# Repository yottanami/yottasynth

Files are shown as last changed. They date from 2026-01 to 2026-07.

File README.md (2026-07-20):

# Yottasynth: Open Hardware Touchscreen Synth with Persian/Iranian Tunings

Yottasynth is an open hardware touchscreen synth with a compact page-based control surface, five context-sensitive knobs, an arpeggiator, a step sequencer, and support for Persian/Iranian music tunings.

یوتاسینث یک سینت‌سایزر دیجیتال متن‌باز با رابط لمسی، سکوئنسر، آرپژیاتور و پشتیبانی از کوک‌های موسیقی ایرانی است. این ساز امکان انتخاب کوک‌های مرتبط با دستگاه‌ها و آوازهای ایرانی را فراهم می‌کند تا برای اجرا و طراحی صدا در فضای موسیقی ایرانی مناسب‌تر باشد.

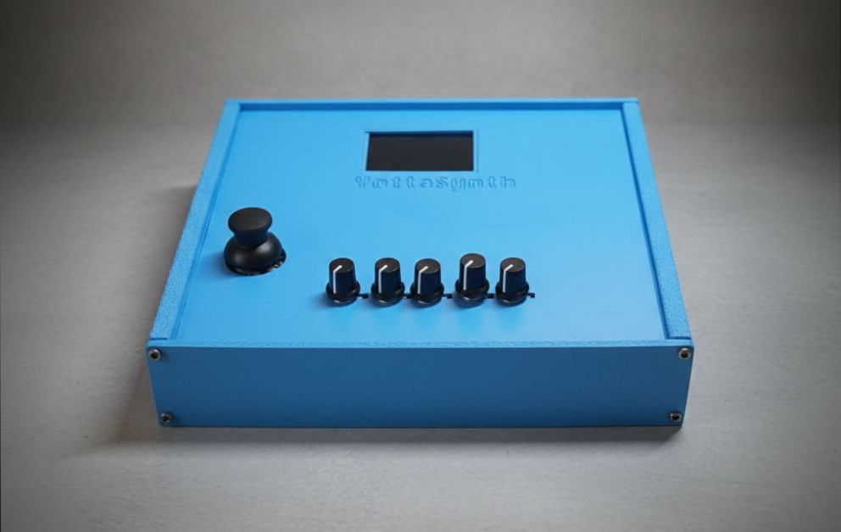
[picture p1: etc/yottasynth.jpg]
Yottasynth prototype

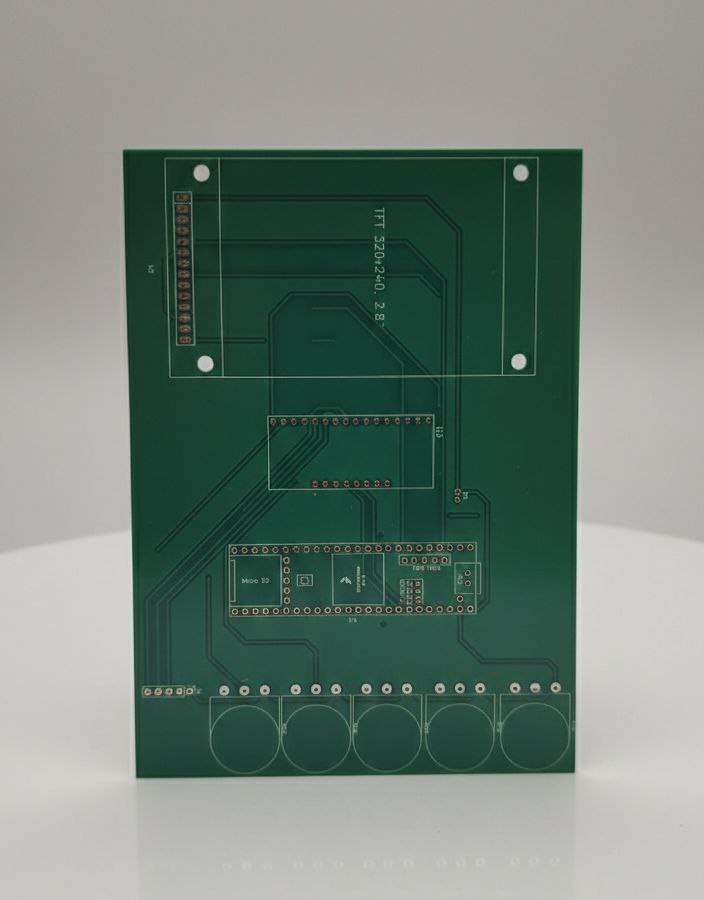
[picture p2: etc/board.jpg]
Yottasynth board


## What It Is

The current firmware is a playable mono synth instrument with:

- a touch-first panel UI
- five context-sensitive knobs
- arpeggiator
- 16-step sequencer
- three effect modes: `Echo`, `Reverb`, and `Drive`
- selectable Persian scale tunings

## Current Features

- `PLAY`, `OSC`, `FILT`, `MOD`, `FX`, `ARP`, `SEQ`, and `SET` pages
- mono synth voice with dual oscillators, noise, filter, envelope, glide, and LFO
- page-specific touch actions and knob mappings
- internal BPM transport, or external MIDI clock sync over USB
- arpeggiator with mode, division, gate, octave range, and latch
- 16-step sequencer with step selection, bank switching, swing, and live MIDI record
- effect editing with page-dependent controls
- output volume, tuning, and clock-source (internal / external) selection from the settings page
- Persian scale support through alternate tunings
- touch screen used for navigation and `OK / Confirm` actions

## Persian / Iranian Tunings

The current tuning list includes:

- `Standard` (`استاندارد`)
- `Shur` (`شور`)
- `Abuata` (`ابوعطا`)
- `Dashti` (`دشتی`)
- `Bayat-e Tork` (`بیات ترک`)
- `Afshari` (`افشاری`)
- `Segah` (`سه‌گاه`)
- `Chahargah` (`چهارگاه`)
- `Homayun` (`همایون`)
- `Bayat-e Esfahan` (`بیات اصفهان`)
- `Nava` (`نوا`)
- `Mahur` (`ماهور`)
- `Rast-Panjgah` (`راست‌پنجگاه`)

## How It Works

Yottasynth is organized as one compact panel split into pages. The touch screen is used to switch pages and trigger actions, while the five physical knobs always control the five parameters shown on screen for the current page.

In normal use, a MIDI controller feeds notes into the synth engine through USB host MIDI. You shape the sound on the synth pages, switch to `ARP` for rhythmic note patterns, use `SEQ` for step programming and live record, and adjust global volume or tuning in `SET`. When a destructive action needs confirmation, a second tap on the armed button acts as `OK`.

The transport (sequencer and arpeggiator) normally runs on its own internal BPM. Set `SYNC` to `EXT` on the `SET` page to slave it to an external MIDI clock over USB instead. Two USB paths are supported without any hardware change:

- the **USB host port** (alongside the keyboard, through a USB hub) for standalone gear such as an Ableton Move
- the **native USB port** (the same cable used to upload firmware) for a computer / DAW such as Ableton Live

In external mode the synth follows the host's tempo and its start / stop / continue transport.

## Interface Summary

- top bar: page title plus compact status
- middle panel: parameter cards and touch actions
- bottom bar: eight color-coded tabs

Page layout:

- `PLAY`: quick performance controls
- `OSC`: oscillator mix, noise, octave, detune, and waveform changes
- `FILT`: filter and envelope shaping
- `MOD`: LFO, bend range, and modulation target
- `FX`: echo, reverb, or drive editing
- `ARP`: arpeggiator setup
- `SEQ`: 16-step sequencing
- `SET`: output volume, tuning, clock source (internal / external sync), and input test entry

## User Guide

For a user-perspective walkthrough of the panel, controls, pages, and sequencing flow, see [docs/user-guide.md](docs/user-guide.md).

For developer-facing documentation of the firmware structure and code, see:

- [docs/README.md](docs/README.md)
- [docs/source-reading-guide.md](docs/source-reading-guide.md)
- [docs/codebase-guide.md](docs/codebase-guide.md)

## Screenshots

Yottasynth interface overview

To export screenshots of the current screen pages without running the device firmware:

```bash
python3 scripts/generate_screenshots.py
```

This writes one SVG per page, a stitched `overview.svg` for the README, and a simple preview index into `docs/screenshots/`.

## Hardware + 3D

- board design files: `etc/board/`
- touch-driven panel firmware: `src/`
- headers and shared definitions: `include/`
- project docs: `docs/`

## Status

This is still an active work-in-progress project, but the firmware already implements the main instrument shell and core performance workflow.

## Contributing

Contributions are welcome. Feel free to open an issue or a PR if you want to help with firmware, hardware, or design.

## Issues

https://github.com/yottanami/yottainst/issues/new

## Contact

https://yottanami.com

## Support

- GitHub Sponsors: https://github.com/sponsors/yottanami
- Ko-fi: https://ko-fi.com/yottanami

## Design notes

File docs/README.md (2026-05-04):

# Yottasynth Documentation

This folder contains the project documentation for two different audiences:

1. people who want to use the instrument
2. people who want to understand or change the firmware

If you are new to the codebase, read the documents in this order:

1. [User Guide](user-guide.md)
2. [Source Reading Guide](source-reading-guide.md)
3. [Codebase Guide](codebase-guide.md)

## Document Map

### End-user documentation

- [User Guide](user-guide.md)
  Explains the screen, pages, knobs, touch controls, and normal playing workflow.

### Developer documentation

- [Source Reading Guide](source-reading-guide.md)
  Explains the C++ language features and embedded-programming patterns used by this firmware.

- [Codebase Guide](codebase-guide.md)
  Explains how the firmware is structured, how data moves through it, and what each active file is responsible for.

- [Synth V1 Plan](synth-v1-plan.md)
  Historical product/UI planning notes for the current panel concept.

## Scope Notes

This repository contains both:

- the current firmware implementation in `src/` and `include/`
- older prototype code in `lib/`

The active firmware entry point is [`src/main.cpp`](../src/main.cpp). The `lib/` directory is still useful for historical context, but it is not the main implementation path described by the current firmware docs.

## Repository Areas

- `src/`
  Main firmware implementation.

- `include/`
  Header files for the active firmware.

- `docs/`
  Project documentation.

- `etc/`
  Hardware photos, board design files, and related assets.

- `lib/`
  Legacy prototype code and earlier experiments.

- `test/`
  Placeholder test directory. There are currently no automated firmware tests in this repository.

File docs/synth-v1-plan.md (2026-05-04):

# Yottasynth Synth V1

## Summary

This document is the practical reference for the current panel structure and touch UI.

The implemented interface provides:

- eight tabs
- five context-sensitive pots
- joystick push-button as `OK / Confirm`
- one main panel area that changes by page
- a dedicated sequencer grid view

## Hardware Control Map

Source of truth note:

- the active mux and panel mapping in code is the valid mapping
- board design documents may still reflect an older mux wiring layout
- if there is any conflict, follow the current firmware implementation

- mux select pins: `14 / 15 / 16 / 17`
- mux signal pin: `22`
- knob 1: `C2`
- knob 2: `C4`
- knob 3: `C1`
- knob 4: `C5`
- knob 5: `C0`
- joystick push button: `C7`
- touch screen: primary navigation and detailed editing

Joystick axes are intentionally unused in v1.

## UI Structure

- `PLAY`
  - pots: cutoff, resonance, glide, arp gate, BPM
  - touch actions: run/stop, arp toggle, unused slot, panic
- `OSC / MIX`
  - pots: osc1 mix, osc2 mix, noise mix, octave, detune
  - touch actions: osc1 previous wave, osc1 next wave, osc2 previous wave, osc2 next wave
- `FILTER / AMP`
  - pots: cutoff, resonance, attack, decay, release
  - touch actions: sustain down, sustain up, short envelope preset, long envelope preset
- `MOD`
  - pots: LFO rate, LFO depth, glide, bend range, LFO target
  - touch actions: LFO off, filter target, pitch target, zero depth
- `FX`
  - pots: mode-dependent effect parameters
  - touch actions: bypass, echo, reverb, drive
- `ARPEGGIATOR`
  - pots: BPM, division, gate, octave range, mode
  - touch actions: enable, latch, run/stop, clear held notes
- `SEQUENCER`
  - pots: BPM, pattern length, swing, selected-step note, selected-step gate
  - touch actions: run/stop, record arm, bank switch, clear pattern
  - touch step pads: select a step on first tap, toggle active state on second tap
- `SETTINGS`
  - pots: output volume, tuning
  - touch actions: input test page

The `OK` button confirms pattern clear when the sequencer page is waiting for confirmation.

## Interaction Rules

- the five pots stay active and remap by page
- the touch screen is the main navigation and action surface
- the joystick `OK` button is reserved for confirmations such as sequence clear
- sequencer step buttons use first tap to select and second tap to toggle
- page accent colors should stay stable across the whole interface

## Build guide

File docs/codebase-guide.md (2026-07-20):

# Yottasynth Codebase Guide

This document explains how the current firmware is structured, how the main modules work, and how the code is organized for someone who is new both to the project and to embedded C++.

It focuses on the active firmware path:

- [`src/`](../src/)
- [`include/`](../include/)

It also points out where the repository still contains older prototype code.

## 1. What This Firmware Does

At a high level, the firmware turns a Teensy-based hardware instrument into a touch-first mono synthesizer with:

- USB host MIDI input
- a five-knob control surface through a multiplexer
- a touchscreen interface built with LVGL
- a mono synth voice with two oscillators, noise, filter, envelope, glide, and LFO
- a transport shared by an arpeggiator and step sequencer
- three effect modes: echo, reverb, and drive
- selectable Persian/Iranian-inspired tuning tables

The main idea is simple:

1. read physical inputs
2. update application state
3. render the UI from that state
4. drive the synth engine from that state
5. repeat forever

## 2. Current Architecture

The active runtime looks like this:

```text
Hardware inputs
  |- touch controller
  |- five pots wired directly to analog pins 14/15/16/17/22
  |- USB MIDI device
  v
Input and event layers
  |- main.cpp touch callback
  |- ControlInput
  |- PlayMode
  v
Shared state and control logic
  |- AppState
  |- Settings
  |- MainMenu
  |- PerformanceEngine
  v
Audio layers
  |- Synth
  |- audio_setup.cpp audio graph + effects
  v
Audio codec / I2S output
```

Two design choices define the whole project:

1. `AppState` is the central shared data model.
2. `main.cpp` coordinates subsystems in a single cooperative loop.

## 3. Repository Structure

### Active firmware

- [`src/main.cpp`](../src/main.cpp)
  Boot sequence, LVGL setup, touchscreen input bridge, main runtime loop.

- [`src/app_state.cpp`](../src/app_state.cpp) and [`include/app_state.h`](../include/app_state.h)
  Central application state and label helpers.

- [`src/control_input.cpp`](../src/control_input.cpp) and [`include/control_input.h`](../include/control_input.h)
  Multiplexer-based knob and confirm-button scanning.

- [`src/play_mode.cpp`](../src/play_mode.cpp) and [`include/play_mode.h`](../include/play_mode.h)
  USB host MIDI stack and MIDI event registration.

- [`src/performance_engine.cpp`](../src/performance_engine.cpp) and [`include/performance_engine.h`](../include/performance_engine.h)
  Transport, arpeggiator, sequencer, held notes, and generated note timing.

- [`src/synth.cpp`](../src/synth.cpp) and [`include/synth.h`](../include/synth.h)
  Voice logic and mapping from patch state to Teensy Audio objects.

- [`src/audio_setup.cpp`](../src/audio_setup.cpp) and [`include/audio_setup.h`](../include/audio_setup.h)
  Audio graph definition, codec initialization, and effect routing.

- [`src/main_menu.cpp`](../src/main_menu.cpp) and [`include/main_menu.h`](../include/main_menu.h)
  LVGL panel UI and page-specific control mapping.

- [`src/input_test_page.cpp`](../src/input_test_page.cpp) and [`include/input_test_page.h`](../include/input_test_page.h)
  Hardware diagnostics page for touch, knobs, spare analog pins, audio self-test, and MIDI status.

- [`include/settings.h`](../include/settings.h) and [`src/settings.cpp`](../src/settings.cpp)
  Small global mode tracker.

- [`include/knob_pins.h`](../include/knob_pins.h)
  Shared multiplexer pin assignments.

- [`include/lv_conf.h`](../include/lv_conf.h)
  LVGL compile-time configuration.

### Documentation and hardware assets

- `docs/`
  Human documentation.

- `etc/`
  Board pictures and KiCad design files.

### Legacy prototype code

- [`lib/synthesizer/`](../lib/synthesizer/)
  Older synth prototype using a different architecture.

- [`lib/ui/`](../lib/ui/)
  Older menu prototype.

- [`lib/settings.h`](../lib/settings.h)
  Older settings singleton that matches the prototype code.

These `lib/` files are useful as history, but they are not the current implementation path described by `src/main.cpp`.

## 4. Build And Platform Context

The build configuration is defined in [`platformio.ini`](../platformio.ini).

Important points:

- target board: `teensy41`
- framework: `arduino`
- upload protocol: `teensy-cli`
- UI libraries: `lvgl`, `TFT_eSPI`, `XPT2046_Touchscreen`
- USB MIDI serial support enabled by `-D USB_MIDI_SERIAL`

From a code-reading perspective, this tells you:

1. the runtime model is Arduino-style
2. graphics are handled by LVGL
3. the screen is an SPI TFT
4. the touch controller is separate from the display
5. the audio path uses the Teensy Audio ecosystem

## 5. Startup Flow

The current boot sequence lives in [`src/main.cpp`](../src/main.cpp).

### 5.1 Global objects created before `setup()`

Several long-lived objects are created at file scope:

- touchscreen driver
- TFT display driver
- LVGL draw buffer
- `play_mode`
- `synth`
- other singleton/global modules in their own `.cpp` files

This is common in embedded firmware. The project assumes there is one instrument and one set of hardware services.

### 5.2 `setup()`

`setup()` performs these steps:

1. starts serial output
2. initializes LVGL
3. initializes the TFT display
4. initializes the XPT2046 touch controller
5. creates LVGL display and input devices
6. renders the main UI with `main_menu.render()`
7. starts control-input scanning with `control_input.begin()`
8. initializes the audio graph with `setupAudio()`
9. stores audio status in `AppState`
10. initializes the synth voice with `synth.setup()`
11. applies initial output volume
12. starts USB host MIDI with `play_mode.setup()`
13. gives the synth pointer to `performance_engine.begin(&synth)`

This is the system assembly phase. After `setup()`, all major services are alive.

### 5.3 `loop()`

`loop()` runs forever and does the following:

1. refreshes transient MIDI status in `AppState`
2. checks the high-level `Mode` from `Settings`
3. if input-test mode is active:
   runs the diagnostic page loop
4. otherwise:
   updates knob/button input
   sends pot changes into `MainMenu`
   sends confirm-button presses into `MainMenu`
   polls USB MIDI
   updates transport/arpeggiator/sequencer timing
   applies patch and effects to audio
   runs synth smoothing/modulation logic
   updates audio status in `AppState`
5. listens for serial `!` to reboot into bootloader
6. lets `MainMenu` refresh the UI if needed
7. advances LVGL ticks and timers

This is a cooperative system. No module owns the CPU for long. Each module does a small amount of work and returns quickly.

## 6. Shared State Model

The central state type is declared in [`include/app_state.h`](../include/app_state.h).

### 6.1 Why `AppState` exists

Instead of letting each module keep its own disconnected state, the firmware keeps most instrument state in one place:

- patch parameters
- transport state
- arpeggiator state
- effect state
- sequencer data
- UI state
- MIDI status
- audio status

This makes the UI, performance logic, and audio logic coordinate through shared data instead of directly calling each other all the time.

### 6.2 Main structs inside `AppState`

#### `PatchState`

Contains the sound-design parameters:

- oscillator mix
- oscillator waveforms
- noise mix
- oscillator octave offset
- detune
- filter cutoff and resonance
- ADSR envelope
- LFO rate and depth
- LFO target
- glide
- pitch-bend range
- tuning selection

This is the heart of the sound patch.

#### `TransportState`

Contains tempo and step timing state:

- BPM
- whether the transport is running
- swing amount
- current step index
- clock source (`INTERNAL` or `EXTERNAL`)
- whether an external clock is currently present

This transport is shared by both the sequencer and arpeggiator. When the clock
source is `EXTERNAL`, step timing is driven by incoming MIDI clock ticks instead
of the internal `micros()` scheduler (see section 10.2).

#### `ArpState`

Contains:

- enabled flag
- latch flag
- arp mode
- octave range
- rhythmic division
- gate percentage

#### `FxState`

Contains:

- enabled flag
- current effect mode
- per-mode parameter blocks for echo, reverb, and drive

#### `SequencerState`

Contains:

- enabled flag
- record-arm flag
- pattern length
- current playhead
- selected step
- visible bank
- `SequenceStep steps[16]`

Each `SequenceStep` stores:

- `active`
- `tie`
- `note`
- `gate`

The `tie` field exists but is not yet actively used by the current step-playback logic.

#### `UiState`

Contains:

- current page
- dirty flag
- whether the input-test page is being shown
- whether the sequencer clear action is waiting for confirmation

The dirty flag is important. It tells the UI when it must redraw instead of constantly rebuilding labels every loop.

#### `MidiStatus`

Contains:

- whether a USB MIDI device is connected
- vendor and product IDs
- last note and velocity
- recent-note timing info for transient status display

#### `AudioStatus`

Contains:

- whether the codec started successfully
- whether audio self-test is currently active
- output volume

### 6.3 `AppState` helper methods

Important methods:

- `setPage`
  Changes page and clears transient UI flags.

- `setInputTestVisible`
  Shows or hides diagnostic mode inside the UI.

- `markDirty`
  Requests a UI refresh.

- `currentMode`
  Converts UI page/test state into a higher-level `Mode`.

- `updateMidiDevice`
  Updates MIDI connection info and marks the UI dirty when needed.

- `registerMidiNote`
  Stores the most recent incoming note for status display.

- `refreshTransientStatus`
  Clears “recent note” status after a timeout.

- `updateAudioStatus`
  Keeps codec and self-test status in sync.

- `setOutputVolume`
  Clamps and stores volume in normalized form.

### 6.4 Why there is also a `Settings` singleton

`Settings` is a much smaller singleton that only tracks the current high-level mode:

- `MENU`
- `SYNTHESIZER`
- `SEQUENCER`
- `ARPEGGIATOR`
- `INPUT_TEST`

In the current code, `MainMenu` writes this mode by asking `AppState::currentMode()`.

You can think of `Settings` as a lightweight “what subsystem loop branch should run right now?” flag.

## 7. Input System

The firmware has three main input sources:

1. touch screen
2. multiplexed analog controls
3. USB MIDI

### 7.1 Touch input in `main.cpp`

The touch handling in [`src/main.cpp`](../src/main.cpp) is more than a thin hardware wrapper.

It adds filtering and confirmation rules:

- raw touches must be inside calibrated ranges
- pressure thresholds are used
- touches must be stable for more than one sample before being accepted
- movement is also filtered before a new touch point is committed

This is done to avoid noisy touch behavior on the resistive touch controller.

Key helper functions:

- `touchPointInRange`
- `touchPointsClose`
- `storePendingTouch`
- `commitTouchSample`
- `holdLastTouch`
- `releaseTouch`

The LVGL input callback is `my_touchpad_read`. It translates a raw `TS_Point` into:

- `LV_INDEV_STATE_PRESSED` or `LV_INDEV_STATE_RELEASED`
- screen coordinates in the `480x320` display space

The same touch information is also forwarded to `input_test_page.updateTouch(...)` so the diagnostic page can display raw and mapped touch data.

### 7.2 Knobs and OK button in `ControlInput`

[`src/control_input.cpp`](../src/control_input.cpp) reads the five knobs directly from Teensy analog pins `14/15/16/17/22`.

Important implementation details:

- knob pins come from [`include/knob_pins.h`](../include/knob_pins.h)
- ADC resolution is set to 12 bits
- each channel is oversampled and averaged
- a smoothing filter reduces jitter
- a threshold decides whether a pot change is worth reporting
- the button is debounced in software

#### Pot mapping

The active runtime mapping is:

- knob 1 -> channel `C2`
- knob 2 -> channel `C4`
- knob 3 -> channel `C1`
- knob 4 -> channel `C5`
- knob 5 -> channel `C0`
- OK button -> channel `C7`

This mapping is defined by `ControlInput::kPotChannels` and `kButtonChannel`.

#### Important methods

- `begin`
  Configures the knob analog pins and captures initial pot values.

- `update`
  Reads all controls, filters them, and records pending changes.

- `consumePotChange`
  Returns one pot change exactly once.

- `consumeOkPress`
  Returns one debounced confirm-button press exactly once.

This “consume” pattern is useful because it decouples scanning from action handling.

### 7.3 Hardware diagnostic mode in `InputTestPage`

[`src/input_test_page.cpp`](../src/input_test_page.cpp) provides a service/debug page inside the UI.

It can show:

- touch coordinates and raw pressure
- audio self-test state
- MIDI connection state
- live multiplexer values
- live direct analog pin values
- min/max movement ranges since last reset

It uses a slower, diagnostic-oriented scanning model than the normal control path.

Important details:

- it can start a short audio self-test by calling `synth.startSelfTest()`
- it resets activity ranges when requested
- it samples the knob pins and probe pins periodically
- it samples a set of direct analog pins separately

#### Important caution

The diagnostic page still contains some older “KiCad pot guess” labels and channel assumptions that do not fully match the active runtime control mapping in `ControlInput`.

For real instrument behavior, the source of truth is:

- [`include/control_input.h`](../include/control_input.h)
- [`src/control_input.cpp`](../src/control_input.cpp)

That means the input-test page is best understood as a hardware probing tool, not as the definitive live-control map.

## 8. MIDI Input Layer

The MIDI layer is implemented by [`src/play_mode.cpp`](../src/play_mode.cpp).

Despite the name, this file is primarily a USB host MIDI service.

### 8.1 What it creates

It creates global USB host stack objects:

- `USBHost myusb`
- two `USBHub` objects
- two `MIDIDevice` instances (`midi1`, `midi2`)

Two host-side `MIDIDevice` instances let a keyboard and a clock-sending device
(for example an Ableton Move) coexist through a USB hub on the single host port;
either can carry notes or clock.

MIDI also arrives from the **device side**: because the build enables
`-D USB_MIDI_SERIAL`, the Teensy enumerates as a USB-MIDI device on its native
port, so a computer / DAW such as Ableton Live can send notes and clock over the
same cable used to upload firmware. That stream is read through the core
`usbMIDI` object.

### 8.2 What `setup()` does

It:

1. waits briefly before enabling USB host power
2. starts the USB host stack
3. registers callback handlers for many MIDI message types

A `registerHandlers(...)` template applies the common handlers (notes, pitch
bend, and clock / start / continue / stop) uniformly to `midi1`, `midi2`, and the
device-side `usbMIDI`. Callbacks with real behavior:

- note on
- note off
- pitch bend
- clock, start, continue, stop (transport sync, active only when clock source is `EXTERNAL`)

Most others are stubbed out with unused-parameter handling.

### 8.3 Important data flow

When MIDI note-on arrives:

1. `AppState` stores recent-note status
2. `PerformanceEngine::onMidiNoteOn(...)` is called

When MIDI note-off arrives:

1. `PerformanceEngine::onMidiNoteOff(...)` is called

When pitch bend arrives:

1. `PerformanceEngine::onMidiPitchBend(...)` is called

When a clock / start / continue / stop message arrives:

1. the matching `PerformanceEngine::onMidiClockTick / onMidiStart / onMidiContinue / onMidiStop` is called
2. these only drive the transport when the clock source is `EXTERNAL`

### 8.4 Polling model

`PlayMode::loop()` must be called continuously.

It performs:

- `myusb.Task()`
- `midi1.read()` and `midi2.read()` (host side)
- `usbMIDI.read()` (device side)
- `AppState::updateMidiDevice(...)`

This is an important embedded pattern: the callbacks are only triggered because the code actively polls the device in the main loop.

## 9. UI Layer

The UI is implemented in [`src/main_menu.cpp`](../src/main_menu.cpp).

This is the largest file in the active firmware because it combines:

- LVGL object creation
- screen layout
- page labels
- value formatting
- control mapping
- touch-action logic

### 9.1 UI layout

The screen has three bands:

- top status bar
- content area
- bottom tab bar

Inside the content area, the main page can show:

- five pot cards and four action buttons
- sequencer overview + eight step buttons
- or the input-test page

### 9.2 Why the UI uses a dirty flag

`MainMenu::loop()` only refreshes when `state.ui.dirty` is true.

That matters because:

- embedded display updates are relatively expensive
- most loop iterations do not need a full UI refresh

This pattern helps keep the UI responsive without redrawing everything every frame.

### 9.3 Main responsibilities

#### `render()`

Creates all LVGL widgets once:

- root container
- top bar
- content panel
- input-test panel
- pot cards
- action buttons
- sequencer buttons
- tab bar

This function mostly describes structure and styling.

#### `handlePotChange(index, value)`

Maps the five physical knobs to different parameters depending on the active page.

This is one of the central project behaviors. The same five physical controls mean different things on different pages.

#### `handleAction(action_index)`

Maps touch buttons to page-specific actions.

Examples:

- waveform selection on `OSC / MIX`
- LFO target selection on `MOD`
- effect mode selection on `FX`
- transport and record actions on `SEQ`

#### `handleOkPress()`

Currently only confirms sequence clear when the UI is waiting for `OK`.

#### `refresh*()` methods

These update different parts of the screen:

- status bar
- tabs
- pot cards
- action buttons
- sequencer buttons
- visibility of page-specific panels

### 9.4 Page logic

Each page has:

- five pot labels
- five pot value formatters
- up to four touch actions

That logic is distributed through:

- `potName`
- `formatPotValue`
- `refreshActionButtons`
- `handlePotChange`
- `handleAction`

This is a practical pattern for a fixed control surface. Instead of modeling every page as its own class, the project keeps one UI object and switches behavior by `PageId`.

### 9.5 Sequencer UI behavior

The sequencer page has custom behavior:

- eight step buttons are shown at a time
- `visible_bank` selects steps `1..8` or `9..16`
- first tap selects a step
- second tap on the selected step toggles its active state
- a cooldown prevents accidental multiple touch actions

The sequencer also has a two-step clear flow:

1. touch `CLEAR`
2. press the physical OK button

This is implemented with `state.ui.confirm_clear_sequence`.

### 9.6 Important implementation detail

The button labeled `PANIC` on the `PLAY` page currently calls `performance_engine.stopTransport()`.

That stops transport-driven playback, but it is not a full “all notes off everywhere” implementation in the current code.

## 10. Performance Logic Layer

The musical event scheduler lives in [`src/performance_engine.cpp`](../src/performance_engine.cpp).

This file answers questions such as:

- if a MIDI note comes in, should it play directly?
- should the arpeggiator consume it?
- should the sequencer record it?
- when should the next step happen?
- how long should a generated note stay on?

### 10.1 Core responsibilities

- remember held MIDI notes
- schedule transport steps
- run arpeggiator note generation
- run sequencer note generation
- manage note gate durations for generated notes
- forward note events to `Synth`

### 10.2 Transport timing

`stepIntervalUs(...)` computes the duration of one transport step in microseconds.

Important details:

- BPM is clamped to a minimum of `40`
- one step is treated as a sixteenth note
- swing alternates the duration of even and odd steps

This means the transport is grid-based and lightweight rather than sample-accurate or DAW-style complex.

The work of triggering a single step (playhead update, sequencer/arp handling,
step-index increment) lives in `fireStep()`. Internal timing calls it from
`advanceTransportStep()` after computing the next due time; external sync calls it
directly from clock ticks.

#### External clock sync

When the clock source is `EXTERNAL`, the internal `micros()` scheduler is skipped
and the transport is driven by incoming MIDI clock instead:

- MIDI clock is `24` PPQN, so `6` ticks advance one sixteenth-note step
  (`kClocksPerStep`)
- `onMidiClockTick()` estimates BPM from the spacing between ticks (smoothed) and
  writes it back into `TransportState`, so gate lengths and the BPM readout stay correct
- `onMidiStart` / `onMidiContinue` / `onMidiStop` map the host transport onto
  `transport.running`
- if clock messages stop arriving (~0.5s timeout) `ext_clock_present` clears and
  the transport stops

### 10.3 Update loop

`PerformanceEngine::update()`:

1. syncs transport state changes
2. releases generated notes whose gate time expired
3. if the clock source is `EXTERNAL`:
   skips internal step scheduling (steps fire from clock ticks) and only checks for clock dropout
4. otherwise, if transport is running:
   advances one or more due steps

The code includes a small safety limit so a slow loop iteration does not spend too long catching up.

### 10.4 MIDI note handling

#### Note-on

The code path depends on current state:

- if self-test is active:
  ignore musical input

- if sequencer is running and record-armed:
  record the note into the current step and also play it

- otherwise:
  add the note to held notes

- if arpeggiator is enabled:
  direct play is mostly suppressed while arp logic owns playback

- if sequencer is running:
  direct play is suppressed

- otherwise:
  play directly through `Synth`

#### Note-off

Similarly:

- remove from held notes
- possibly stop direct playback
- or ignore release if transport-owned playback is active

### 10.5 Arpeggiator behavior

The arpeggiator uses:

- held-note list
- mode
- division
- octave range
- gate percentage

Supported modes:

- `UP`
- `DOWN`
- `UP_DOWN`
- `RANDOM`

`nextArpNote()` chooses the next note and can add octave offsets based on the current transport step.

### 10.6 Sequencer behavior

Each active sequencer step can generate:

- note number
- fixed velocity for generated playback
- gate duration derived from step gate percentage

If a step is inactive, generated playback is cleared.

If record-arm is enabled and MIDI notes arrive while running, `recordStepFromMidi(...)` writes the incoming note into the current playhead step.

### 10.7 Generated notes

The arpeggiator and sequencer produce notes that are separate from physically held input notes.

The engine tracks:

- whether a generated note is active
- which note it is
- when its gate should end

This is why there are dedicated helpers:

- `triggerGeneratedNote`
- `releaseGeneratedNoteIfDue`
- `clearGeneratedNote`

## 11. Synth Voice Layer

The synth voice logic lives in [`src/synth.cpp`](../src/synth.cpp).

This file is the main bridge between `PatchState` and the Teensy Audio objects representing the lead voice.

### 11.1 Important idea

The current playable instrument is essentially a mono lead voice, even though the audio graph declares additional mid/bass/drum objects.

The active `Synth` object is constructed with:

- `lead_waveform1`
- `lead_waveform2`
- `lead_pink`
- `lead_filter`
- `lead_envelope`

So the current musical firmware uses the lead chain only.

### 11.2 What `setup()` does

It initializes:

- oscillator pulse widths
- oscillator waveforms
- lead mixer gains
- filter defaults
- envelope defaults
- current note and frequencies
- patch application

It also captures an initial `last_update_us_` timestamp used for glide/update calculations.

### 11.3 Patch application

`applyPatch(const PatchState &patch)` updates sound parameters on the audio objects.

It handles:

- waveform changes
- oscillator/noise mix
- filter frequency and resonance
- ADSR envelope values
- live voice refresh if a note is already sounding

Important design detail:

- UI and state store normalized values
- `Synth` converts them into real audio-domain values

Examples:

- cutoff is converted with an exponential mapping to hertz
- ADSR normalized values are mapped to milliseconds
- resonance is mapped into the filter’s expected range

### 11.4 Note stack behavior

The synth keeps a small note buffer of size `8`.

When a new note-on arrives:

- duplicate entries are removed
- the note is appended if there is room
- the newest note becomes the current note

When note-off arrives:

- the released note is removed
- if other notes remain, the most recent remaining note becomes active
- if none remain, the envelope is released

This is a mono last-note-priority design.

### 11.5 Glide

If glide is low, frequency jumps directly to the target.

If glide is higher, the current frequency moves gradually toward the target frequency in `loop()`.

This happens separately from note scheduling. The scheduler decides which note to play, and the synth decides how smoothly to move to it.

### 11.6 LFO behavior

The synth supports two LFO targets:

- filter
- pitch

The modulation is generated as a triangle shape.

Important implementation detail:

`updateModulation()` advances phase using a fixed `0.001f` seconds per loop iteration rather than the measured loop delta.

That means the LFO is simple and practical, but not mathematically tied to exact real elapsed time in the most precise way.

### 11.7 Tuning system

The file defines several cent tables:

- standard equal temperament
- Shur
- Abuata
- Afshari
- Segah
- Chahargah
- Homayun
- Bayat-e Esfahan
- Mahur
- Rast-Panjgah

Some tuning IDs intentionally reuse the same cent table in the current implementation.

`noteToFrequency(...)` works like this:

1. choose the cent table for the selected tuning
2. split MIDI note into note class and octave
3. measure relative to `C4 = 261.63 Hz`
4. compute the final frequency with `powf(2.0f, octave_ratio)`

This is one of the project’s most distinctive musical features.

### 11.8 Self-test mode

The synth can temporarily enter a self-test mode:

- both oscillators become sine waves
- fixed test frequencies are used
- the envelope is forced on
- the test auto-stops after about `1200 ms`

This is triggered by the input-test page and is useful for verifying that the audio path works.

## 12. Audio Graph And Effects

The audio graph is defined in [`src/audio_setup.cpp`](../src/audio_setup.cpp) with declarations mirrored in [`include/audio_setup.h`](../include/audio_setup.h).

### 12.1 Why the file is so large

Most of the file is generated object wiring from the Teensy Audio System Design Tool.

That includes:

- waveform sources
- noise sources
- filters
- mixers
- envelopes
- delay
- reverb
- waveshaper
- bitcrusher
- final stereo output

Generated audio wiring files are usually large because every connection is explicit.

### 12.2 Important practical interpretation

Although many voices are declared:

- lead
- mid
- bass
- drum

the current firmware actively drives the lead voice path only.

The rest of the audio graph is best understood as reserved or prototype structure that could support expansion later.

### 12.3 `setupAudio()`

This function:

1. allocates Teensy audio memory
2. enables the SGTL5000 codec
3. sets codec output levels
4. builds the drive waveshaper curve
5. initializes mixer balances
6. initializes delay times
7. initializes reverb defaults
8. initializes bitcrusher defaults

It returns `true` or `false` depending on whether the audio codec could be enabled.

### 12.4 Output volume

`setOutputVolume(float volume)` is a thin wrapper around `sgtl5000_1.volume(...)`.

The normalized `AppState` value remains the UI/state representation, while this function applies the real codec setting.

### 12.5 Effect application

`applyFxState(const FxState &fx)` is the effect-routing controller.

It:

- checks whether effects are initialized
- skips work if the effect state has not changed
- handles bypass behavior
- reconfigures routing and parameters for echo, reverb, or drive

#### Echo mode

Controls:

- wet/dry mix
- delay time
- feedback
- left/right ratio
- smear

Implementation techniques:

- two delay taps for stereo feel
- feedback mixer
- some bleed into the reverb input for smear

#### Reverb mode

Controls:

- wet/dry mix
- size
- damping
- predelay
- tone

Implementation techniques:

- delay channel used for predelay
- reverb fed with a tone-dependent balance
- different left/right wet levels

#### Drive mode

Controls:

- wet/dry mix
- drive amount
- tone
- bit crush
- level

Implementation techniques:

- pre-gain into waveshaper
- bitcrusher depth
- sample-rate reduction

### 12.6 Change caching

The function stores the last applied `FxState` and compares the new one with `memcmp(...)`.

That is a performance optimization to avoid reapplying the same settings every loop.

## 13. Page-By-Page Behavior

This section explains what each page changes in code.

### `PLAY`

Knobs:

- cutoff
- resonance
- glide
- arp gate
- BPM

Actions:

- toggle transport
- toggle arpeggiator
- unused button slot
- stop transport

### `OSC / MIX`

Knobs:

- oscillator 1 mix
- oscillator 2 mix
- noise mix
- octave index
- detune

Actions:

- previous/next waveform for oscillator 1
- previous/next waveform for oscillator 2

### `FILTER / AMP`

Knobs:

- cutoff
- resonance
- attack
- decay
- release

Actions:

- sustain down
- sustain up
- short envelope preset
- long envelope preset

### `MOD`

Knobs:

- LFO rate
- LFO depth
- glide
- bend range
- LFO target

Actions:

- LFO off
- filter LFO
- pitch LFO
- depth zero

### `FX`

Knobs depend on current effect mode.

Actions:

- bypass
- select echo
- select reverb
- select drive

### `ARP`

Knobs:

- BPM
- division
- gate
- octave range
- mode

Actions:

- enable
- latch
- toggle transport
- clear held notes

### `SEQ`

Knobs:

- BPM
- length
- swing
- selected step note
- selected step gate

Actions:

- run/stop
- record arm
- bank switch
- arm/confirm clear flow

### `SETTINGS`

Knobs:

- output volume
- tuning

Action:

- open input-test page

## 14. LVGL Configuration

[`include/lv_conf.h`](../include/lv_conf.h) is the LVGL configuration header.

You do not need to read it line by line to understand the firmware logic.

The important high-level facts are:

- color depth is `16`
- the default refresh period is `33 ms`
- LVGL logging is enabled
- the default font is `Montserrat 14`
- the memory pool is configured for embedded use

Treat this file as framework configuration rather than product logic.

## 15. Legacy Code In `lib/`

The repository still contains older prototype code.

### `lib/synthesizer`

This older synth implementation:

- uses a much simpler architecture
- handles MIDI directly inside the synth module
- has its own LFO implementation
- predates the current `AppState + MainMenu + PerformanceEngine + Synth` split

It is useful if you want to see the project’s earlier direction, but it is not the main firmware path now.

### `lib/ui`

This contains an older LVGL menu prototype based on a simpler page/menu model.

The current UI no longer uses this structure.

### Why these files matter

For maintenance, it is important to know they exist so you do not confuse:

- active implementation
- historical prototype

When documenting or modifying current behavior, prefer `src/` and `include/`.

## 16. File-By-File Quick Reference

### Core orchestration

- [`src/main.cpp`](../src/main.cpp)
  Boot, loop, display flush, touch filtering, high-level orchestration.

### State

- [`include/app_state.h`](../include/app_state.h)
  Type definitions for almost all live application state.

- [`src/app_state.cpp`](../src/app_state.cpp)
  State initialization and label/helper implementations.

- [`include/settings.h`](../include/settings.h)
  Small mode singleton.

- [`src/settings.cpp`](../src/settings.cpp)
  Defines the static singleton pointer.

### Hardware input

- [`include/knob_pins.h`](../include/knob_pins.h)
  Shared knob pin numbers.

- [`include/control_input.h`](../include/control_input.h)
  Public API for normal control scanning.

- [`src/control_input.cpp`](../src/control_input.cpp)
  Normal runtime scanning, filtering, and button debounce.

- [`include/input_test_page.h`](../include/input_test_page.h)
  Public API for diagnostic page.

- [`src/input_test_page.cpp`](../src/input_test_page.cpp)
  Diagnostic scanning and UI text generation.

### MIDI and scheduling

- [`include/play_mode.h`](../include/play_mode.h)
  MIDI service declarations.

- [`src/play_mode.cpp`](../src/play_mode.cpp)
  USB host MIDI setup and event callbacks.

- [`include/performance_engine.h`](../include/performance_engine.h)
  Scheduler/arpeggiator/sequencer declarations.

- [`src/performance_engine.cpp`](../src/performance_engine.cpp)
  Musical event timing and generated note logic.

### Sound engine

- [`include/synth.h`](../include/synth.h)
  Mono voice interface.

- [`src/synth.cpp`](../src/synth.cpp)
  Voice implementation, tuning tables, modulation, glide, self-test.

- [`include/audio_setup.h`](../include/audio_setup.h)
  Audio graph declarations and public audio helper functions.

- [`src/audio_setup.cpp`](../src/audio_setup.cpp)
  Audio graph instantiation, codec setup, and effect routing.

### UI

- [`include/main_menu.h`](../include/main_menu.h)
  Main UI class declaration.

- [`src/main_menu.cpp`](../src/main_menu.cpp)
  UI creation, refresh logic, formatting, touch actions, page control mapping.

### Configuration

- [`include/lv_conf.h`](../include/lv_conf.h)
  LVGL compile-time settings.

## 17. Important Implementation Characteristics

These are not bugs by themselves, but they are important to know when working on the project:

1. The system is single-threaded and cooperative.
   Long blocking work in any module will hurt touch response, MIDI timing, and UI updates.

2. `AppState` is the main source of truth.
   If behavior looks wrong, verify whether the state is being updated correctly before blaming audio or UI code.

3. The UI often displays interpreted values, not raw internal values.
   Some labels are approximations for readability.

4. The current playable synth is mono and lead-voice focused.
   The audio graph is larger than the feature set actively exposed today.

5. The input-test page is diagnostic, not the final authority on current control mapping.

6. The repository still contains older architectures in `lib/`.
   Do not accidentally treat them as the active code path.

## 18. Recommended Reading Order For New Contributors

If you want to learn the codebase efficiently:

1. read [`src/main.cpp`](../src/main.cpp) for runtime flow
2. read [`include/app_state.h`](../include/app_state.h) for the data model
3. read [`src/main_menu.cpp`](../src/main_menu.cpp) for control mapping
4. read [`src/performance_engine.cpp`](../src/performance_engine.cpp) for note scheduling
5. read [`src/synth.cpp`](../src/synth.cpp) for sound generation logic
6. read [`src/audio_setup.cpp`](../src/audio_setup.cpp) for audio routing
7. read [`src/input_test_page.cpp`](../src/input_test_page.cpp) only after the main flow is clear

That order follows the most useful path from “what runs” to “what it means” to “how it sounds”.

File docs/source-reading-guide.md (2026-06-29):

# Source Reading Guide

This document explains the C++ and embedded-firmware patterns used in this repository.

The goal is not to teach all of C++. The goal is to make this specific codebase readable.

## The Mental Model

This project is not a desktop application. It is firmware running on a `Teensy 4.1` microcontroller.

That changes the programming model in a few important ways:

1. there is no operating-system style main event loop created for you
2. the code runs continuously after boot
3. hardware is controlled by reading and writing pins
4. many objects are created once and live for the whole lifetime of the device
5. timing is often measured with `millis()` or `micros()` instead of threads or timers

The core firmware shape is:

```cpp
void setup() {
  // Run once at boot.
}

void loop() {
  // Run forever.
}
```

That pattern comes from Arduino and is the center of this project.

## How To Read This Repository

Most active modules use the usual C++ split:

- `.h` file
  Declares types, constants, and function signatures.

- `.cpp` file
  Implements the actual logic.

Example:

- `include/synth.h` declares the `Synth` class.
- `src/synth.cpp` implements the `Synth` class.

## Important C++ Features Used Here

### `enum class`

This project uses `enum class` to represent named choices safely.

Example:

```cpp
enum class FxMode : uint8_t {
  ECHO = 0,
  REVERB,
  DRIVE
};
```

Why this is useful:

- code is easier to read than raw numbers
- the compiler prevents mixing unrelated enums by accident
- it documents the allowed states clearly

You will see this pattern for pages, LFO targets, waveforms, arpeggiator modes, effects, and tunings.

### `struct`

`struct` is used here as a lightweight data container.

Example:

```cpp
struct TransportState {
  uint16_t bpm = 120;
  bool running = false;
  float swing = 0.0f;
  uint8_t step_index = 0;
  ClockSource clock_source = ClockSource::INTERNAL;
  bool ext_clock_present = false;
};
```

In this codebase, structs usually mean:

- “these values belong together”
- “this is state, not behavior”

That is why `AppState` contains many small structs such as `PatchState`, `TransportState`, and `FxState`.

### `class`

Classes in this project usually own behavior.

Examples:

- `ControlInput`
  Reads knobs and the confirm button from the hardware multiplexer.

- `MainMenu`
  Builds and refreshes the touch UI.

- `PerformanceEngine`
  Decides what note should play and when.

- `Synth`
  Applies patch values and drives the audio objects.

In this codebase:

- `struct`
  Mostly data

- `class`
  Mostly behavior plus private internal data

This is not a strict rule in C++, but it is a useful reading shortcut for this project.

### Singleton

This project uses the singleton pattern for global shared state.

Example:

```cpp
AppState &AppState::instance() {
  static AppState state;
  return state;
}
```

Meaning:

- only one `AppState` object exists
- any module can access it through `AppState::instance()`

Why the project does this:

- the firmware has one global instrument state
- many modules need access to the same patch, transport, UI, MIDI, and audio status

You will also see an older singleton-style `Settings` class that stores the high-level mode.

### `static`

`static` appears in several different meanings in C++. In this codebase, the most common ones are:

1. static member functions
2. static local variables
3. file-local helpers in anonymous namespaces

#### 1. Static member functions

Example:

```cpp
static void tabEventHandler(lv_event_t *event);
```

This means the function belongs to the class, but does not operate on a specific object automatically through `this`.

It is useful for callback APIs such as LVGL or MIDI, where a library expects a plain function pointer.

#### 2. Static local variables

Example:

```cpp
static AppState state;
```

This object is created once and reused on later calls.

#### 3. File-local helpers

Example:

```cpp
namespace {
float clampUnit(float value) { ... }
}
```

This anonymous namespace means:

- the helper is private to that `.cpp` file
- other files cannot link to it accidentally

That is a common modern C++ way to say “internal helper for this file only”.

### `extern`

`extern` means “this object exists somewhere else; I only want to refer to it here”.

Example:

```cpp
extern MainMenu main_menu;
```

The header declares the object, and one `.cpp` file creates it:

```cpp
MainMenu main_menu;
```

This pattern is used often in embedded code because many hardware/service objects are global and long-lived.

### References and pointers

You will see both references and pointers.

Reference example:

```cpp
AppState &state = AppState::instance();
```

A reference is like another name for an existing object.

Pointer example:

```cpp
Synth *synth_ = nullptr;
```

A pointer can be empty and later point at an object. `PerformanceEngine` uses a pointer because its `Synth` dependency is attached later in `begin(Synth *synth)`.

Practical reading rule:

- `Type &name`
  This must refer to a real object.

- `Type *name`
  This may be null, so the code often checks it before use.

### Arrays

This codebase uses classic C-style arrays in many places because they are simple and efficient on embedded targets.

Examples:

- `SequenceStep steps[16];`
- `uint8_t held_notes_[kHeldCapacity] = {0};`
- `lv_obj_t *tab_buttons_[kTabCount] = {nullptr, ...};`

This is normal in microcontroller code where fixed sizes are known up front and heap allocation is often avoided.

### Callbacks

A callback is a function you give to a library so the library can call you later.

Examples in this project:

- LVGL touch/button event handlers
- USB MIDI note handlers
- display flush callback for the screen driver
- touch read callback for LVGL input

This is why some functions are `static` and have a library-defined signature.

### `constexpr`

`constexpr` means the value is known at compile time.

Example:

```cpp
static constexpr uint8_t kPotCount = 5;
```

Why it is used here:

- makes code self-documenting
- avoids magic numbers
- keeps values cheap and safe for embedded use

### `uint8_t`, `uint16_t`, `int16_t`

These types come from fixed-width integer headers and are very common in embedded code.

Examples:

- `uint8_t`
  Unsigned 8-bit integer, range `0..255`

- `uint16_t`
  Unsigned 16-bit integer, range `0..65535`

- `int16_t`
  Signed 16-bit integer

Why they matter:

- hardware protocols often expect exact widths
- memory usage is more predictable than with plain `int`

### `byte`

Arduino also defines `byte`. In practice it is similar to `uint8_t`.

This project uses both. That is common in mixed Arduino/C++ codebases.

## The “Global Object” Style

In desktop C++, people often avoid global objects. In embedded firmware, global objects are much more common.

Examples in this project:

- `control_input`
- `main_menu`
- `performance_engine`
- `input_test_page`
- `synth`

This style is used because:

- there is one hardware instrument
- the objects are needed for the whole runtime
- setup order is explicit in `setup()`

## Header Guards

You will often see this at the top of header files:

```cpp
#ifndef SYNTH_H
#define SYNTH_H
...
#endif
```

This prevents the same header from being included more than once during compilation.

## Normalized Values

Many parameters in the project are stored as `float` values between `0.0f` and `1.0f`.

Examples:

- filter cutoff control
- resonance
- effect mix
- output volume

Why this is useful:

- knob input naturally becomes a normalized value
- UI can display it in different ways
- audio code can map it to real ranges later

Example:

- UI or control input stores `0.72f`
- synth code converts it into a real filter frequency
- UI code converts it into a readable label

This separation is important to understand the code structure.

## Time In The Firmware

The project uses:

- `millis()`
  Milliseconds since boot

- `micros()`
  Microseconds since boot

Examples:

- button debounce
- transport scheduling
- status expiry
- touch confirmation
- self-test timeout

This is a common non-blocking embedded pattern:

1. read current time
2. compare it with the previous timestamp
3. run work only when enough time has passed

## Why There Are So Many Helper Functions

Functions such as:

- `clampUnit`
- `bpmFromNormalized`
- `noteName`
- `stepIntervalUs`
- `normalizedToFilterHz`

exist to keep the main logic readable.

When you read a file, treat those helpers as small translation layers:

- raw input to normalized data
- normalized data to human-readable text
- musical data to audio parameters

## How To Read A Module In This Codebase

Use this order:

1. open the header file
   Identify the class, its public functions, and private data members.

2. find the `begin()` or `setup()` function
   This usually tells you how the module is initialized.

3. find the `loop()` or `update()` function
   This usually tells you what the module does repeatedly.

4. read the event handlers
   These show what happens when MIDI arrives, a touch button is pressed, or a knob changes.

5. read helper functions last
   They usually support the main flow rather than define it.

## Project-Specific Reading Tips

### `AppState` is the center

If you are lost, start from `AppState`. It contains most of the instrument’s live state.

### `main.cpp` is the orchestration file

It does not contain the deepest logic, but it shows the order in which subsystems run every frame.

### `MainMenu` translates human actions into state changes

It is best thought of as the control panel layer, not the sound engine.

### `PerformanceEngine` decides what notes happen

It handles the arpeggiator, sequencer timing, held notes, and generated note durations.

### `Synth` turns state into sound settings

It controls oscillator frequencies, waveforms, envelopes, filter settings, pitch bend, and tuning tables.

## Legacy Code Warning

The repository also contains older code in `lib/`.

That code is still useful to study historically, but if you want to understand the current firmware behavior, focus on:

- `src/`
- `include/`

The current active firmware starts in `src/main.cpp`, not in `lib/synthesizer/synthesizer.cpp`.

## Final Reading Strategy

If you want the fastest path to understanding the project, read:

1. [`src/main.cpp`](../src/main.cpp)
2. [`include/app_state.h`](../include/app_state.h)
3. [`src/main_menu.cpp`](../src/main_menu.cpp)
4. [`src/performance_engine.cpp`](../src/performance_engine.cpp)
5. [`src/synth.cpp`](../src/synth.cpp)
6. [`src/audio_setup.cpp`](../src/audio_setup.cpp)

Then use the detailed [Codebase Guide](codebase-guide.md) as the reference while you read the source.

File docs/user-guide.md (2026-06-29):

# Yottasynth User Guide

## Overview

Yottasynth is designed as a compact instrument panel rather than a menu-heavy device. The touch screen handles navigation and discrete actions, while the five panel knobs always edit the five values shown on the current page.

The current playing workflow is:

1. connect a MIDI controller through USB host MIDI
2. choose the page you want from the bottom tab bar
3. use the five knobs for the currently visible parameters
4. use the touch buttons for page actions
5. use the `OK` button when the interface asks for confirmation

## Main Controls

### Touch screen

The touch screen is the main navigation surface.

Use it to:

- switch pages with the bottom tabs
- press action buttons
- select sequencer steps

### Five knobs

The five knobs are always active, but their meaning changes with the current page.

### `OK` button

Use this button only when the instrument asks you to confirm an action.

- `OK / Confirm`

Example:

- confirm sequencer clear when the screen is waiting for confirmation

## Screen Layout

The screen is split into three parts:

- top bar: page name and current status
- center panel: parameter cards, action buttons, or sequencer steps
- bottom bar: eight page tabs

The tabs are:

- `PLAY`
- `OSC`
- `FILT`
- `MOD`
- `FX`
- `ARP`
- `SEQ`
- `SET`

## Pages

### `PLAY`

Use this page for quick sound and transport changes while performing.

Knobs:

- `CUT`
- `RES`
- `GLIDE`
- `A-GATE`
- `BPM`

Touch buttons:

- `RUN/STOP`
- `ARP TOG`
- `PANIC`

## `OSC`

Use this page to shape the source sound.

Knobs:

- `OSC1`
- `OSC2`
- `NOISE`
- `OCT`
- `DETUNE`

Touch buttons:

- `W1 <`
- `W1 >`
- `W2 <`
- `W2 >`

This page balances the oscillators and noise, sets octave and detune, and changes waveforms through the touch controls.

## `FILT`

Use this page for brightness and envelope shape.

Knobs:

- `CUT`
- `RES`
- `ATT`
- `DEC`
- `REL`

Touch buttons:

- `SUS -`
- `SUS +`
- `SNAP`
- `LONG`

`SNAP` and `LONG` act like quick envelope presets.

## `MOD`

Use this page to control the LFO and expressive movement.

Knobs:

- `RATE`
- `DEPTH`
- `GLIDE`
- `BEND`
- `TARGET`

Touch buttons:

- `LFO OFF`
- `FILT LFO`
- `PITCH LFO`
- `DEPTH 0`

## `FX`

Use this page to choose and adjust the active effect.

Touch buttons:

- `BYPASS`
- `ECHO`
- `REVERB`
- `DIRT`

The knobs change meaning depending on the selected effect mode.

### Echo mode

Knobs:

- `MIX`
- `TIME`
- `FDBK`
- `RATIO`
- `SMEAR`

### Reverb mode

Knobs:

- `MIX`
- `SIZE`
- `DAMP`
- `PRE`
- `TONE`

### Drive mode

Knobs:

- `MIX`
- `DRIVE`
- `TONE`
- `CRUSH`
- `LEVEL`

## `ARP`

Use this page to turn held notes into repeating rhythmic patterns.

Knobs:

- `BPM`
- `DIV`
- `GATE`
- `OCT`
- `MODE`

Touch buttons:

- `ENABLE`
- `LATCH`
- `RUN/STOP`
- `CLR HELD`

Typical flow:

1. enable the arp
2. set BPM, division, gate, and mode
3. hold notes on the MIDI controller
4. use latch if you want the pattern to keep running after note release

## `SEQ`

Use this page to create and edit a 16-step monophonic sequence.

Knobs:

- `BPM`
- `LEN`
- `SWING`
- `NOTE`
- `GATE`

Touch buttons:

- `RUN/STOP`
- `REC ARM`
- `BANK`
- `CLEAR`

The sequencer page replaces the normal pot-card view with a step grid:

- eight visible step buttons at a time
- bank 1 shows steps `1-8`
- bank 2 shows steps `9-16`

Step interaction:

1. tap a step once to select it
2. tap the same selected step again to toggle it on or off
3. turn the `NOTE` knob to set its pitch
4. turn the `GATE` knob to set its gate length
5. use `BANK` to reach the other half of the pattern

### Recording into the sequencer

When `REC ARM` is active, incoming MIDI notes can be written into the currently playing step while the transport runs.

### Clearing the sequence

`CLEAR` does not erase immediately.

Current flow:

1. press `CLEAR`
2. the UI waits for confirmation
3. press the `OK` button to confirm

## `SET`

Use this page for global settings.

Knobs:

- `VOL`
- `TUNE`

This page is also where you choose the tuning system.

## Persian Scales and Tunings

Yottasynth includes alternate tunings with Persian music inspired scales.

Available tuning names:

- `Standard`
- `Shur`
- `Abuata`
- `Dashti`
- `Bayat-e Tork`
- `Afshari`
- `Segah`
- `Chahargah`
- `Homayun`
- `Bayat-e Esfahan`
- `Nava`
- `Mahur`
- `Rast-Panjgah`

To change tuning:

1. open `SET`
2. turn the `TUNE` knob
3. stop on the tuning you want

## Syncing to an External Clock

By default the transport runs on its own internal BPM. To slave the sequencer and
arpeggiator to an external MIDI clock instead:

1. open `SET`
2. turn the `SYNC` knob to `EXT`
3. connect the clock source over USB:
   - a standalone device (e.g. Ableton Move) into the USB host port, through a USB
     hub alongside your keyboard, or
   - a computer / DAW (e.g. Ableton Live) over the same USB cable used to upload firmware
4. start playback on the external device

When synced, the top status bar shows `EXT` (or `EXT?` while no clock is arriving),
the displayed BPM follows the incoming clock, and the external device's start /
stop / continue controls drive the transport. Set `SYNC` back to `INT` to return
to the internal clock.

## Quick Start

1. power the instrument
2. connect a MIDI controller through USB host MIDI
3. go to `PLAY` and confirm you have sound
4. adjust oscillator, filter, and modulation pages
5. add echo, reverb, or drive from `FX`
6. use `ARP` for repeating patterns
7. use `SEQ` to build a 16-step phrase
8. switch to `SET` if you want a Persian tuning or a different output volume

## Current Limits

From a user perspective, these are the main current limits:

- the synth is monophonic
- the sequencer is monophonic
- sequence clear uses confirm, but broader preset management is not implemented yet

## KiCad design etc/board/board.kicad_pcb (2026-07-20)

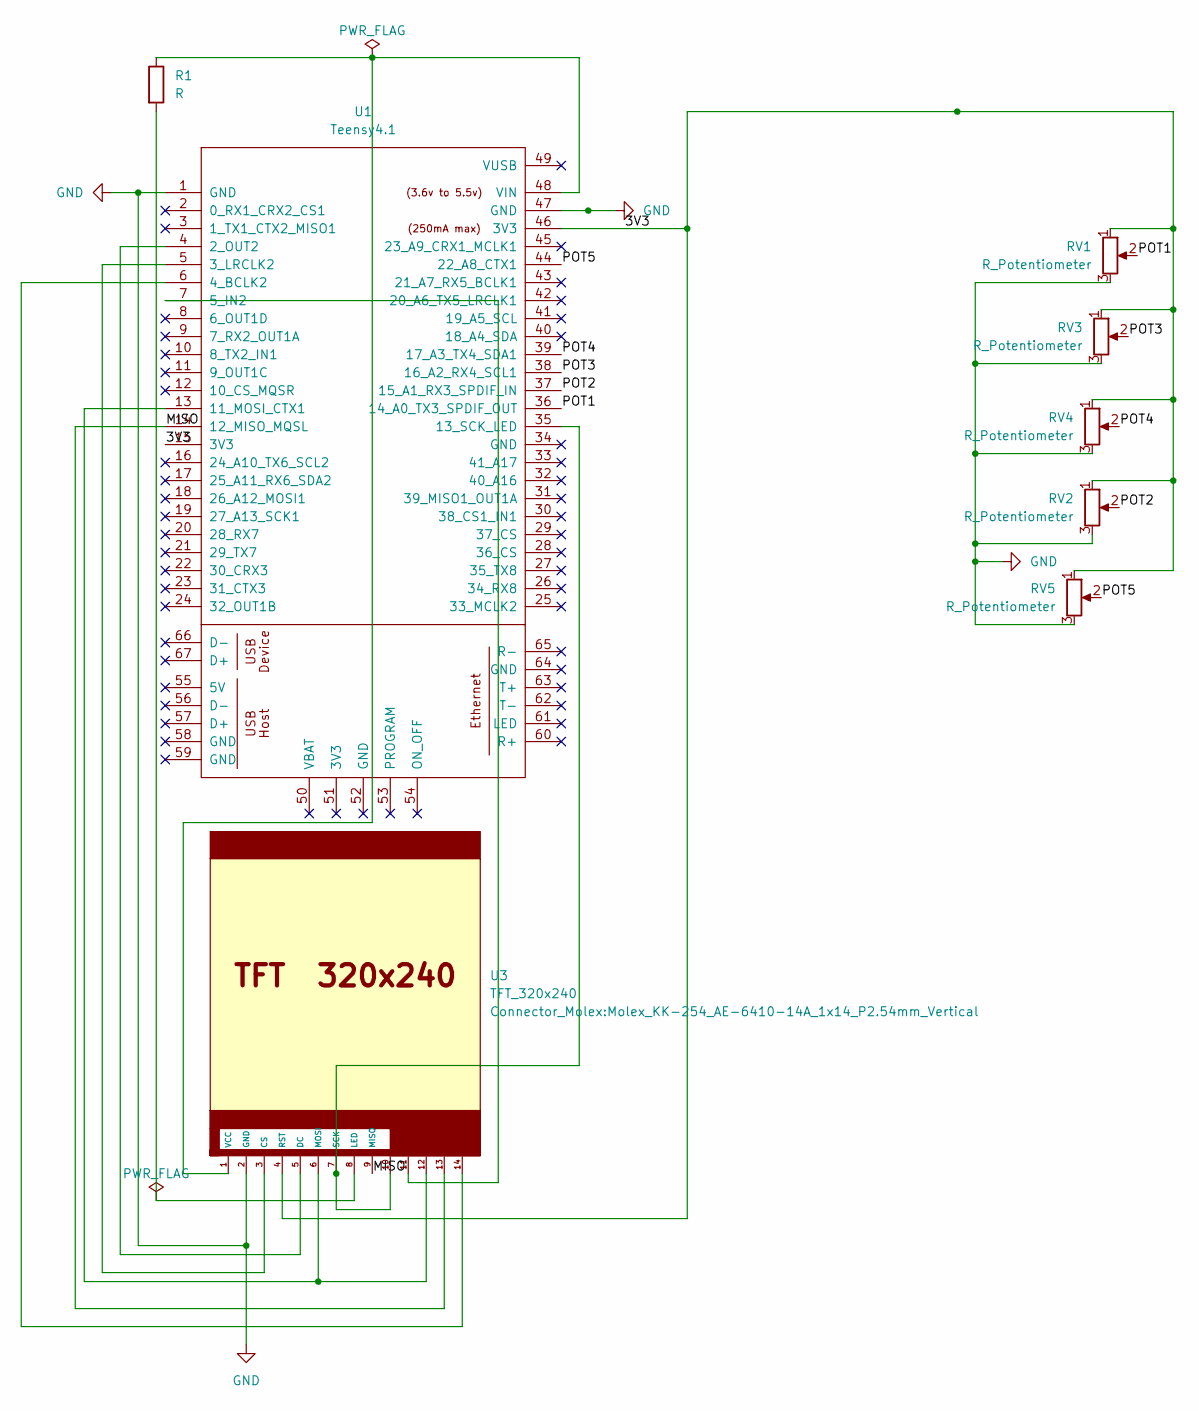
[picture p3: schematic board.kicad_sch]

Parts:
R1: R; R_Axial_DIN0207_L6.3mm_D2.5mm_P2.54mm_Vertical
RV1, RV2, RV3, RV4, RV5: R_Potentiometer; Molex_KK-254_AE-6410-03A_1x03_P2.54mm_Vertical
U1: Teensy4.1; Teensy
U3: TFT_320x240; Molex_KK-254_AE-6410-14A_1x14_P2.54mm_Vertical

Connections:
/3V3: RV1.1, RV2.1, RV3.1, RV4.1, RV5.1, U1.15 (3V3), U1.46 (3V3), U3.4 (RST)
/MISO: U1.14 (12_MISO_MQSL), U3.9 (MISO), U3.13
/POT1: RV1.2, U1.36 (14_A0_TX3_SPDIF_OUT)
/POT2: RV2.2, U1.37 (15_A1_RX3_SPDIF_IN)
/POT3: RV3.2, U1.38 (16_A2_RX4_SCL1)
/POT4: RV4.2, U1.39 (17_A3_TX4_SDA1)
/POT5: RV5.2, U1.44 (22_A8_CTX1)
GND: RV1.3, RV2.3, RV3.3, RV4.3, RV5.3, U1.1 (GND), U1.47 (GND), U3.2 (GND)
unnamed: U1.4 (2_OUT2), U3.5 (DC)
unnamed: U1.5 (3_LRCLK2), U3.3 (CS)
unnamed: U1.6 (4_BCLK2), U3.14
unnamed: U1.7 (5_IN2), U3.11
unnamed: U1.13 (11_MOSI_CTX1), U3.6 (MOSI), U3.12
unnamed: U1.35 (13_SCK_LED), U3.7 (SCK), U3.10
unnamed: R1.1, U1.48 (VIN), U3.1 (VCC)
unnamed: R1.2, U3.8 (LED)

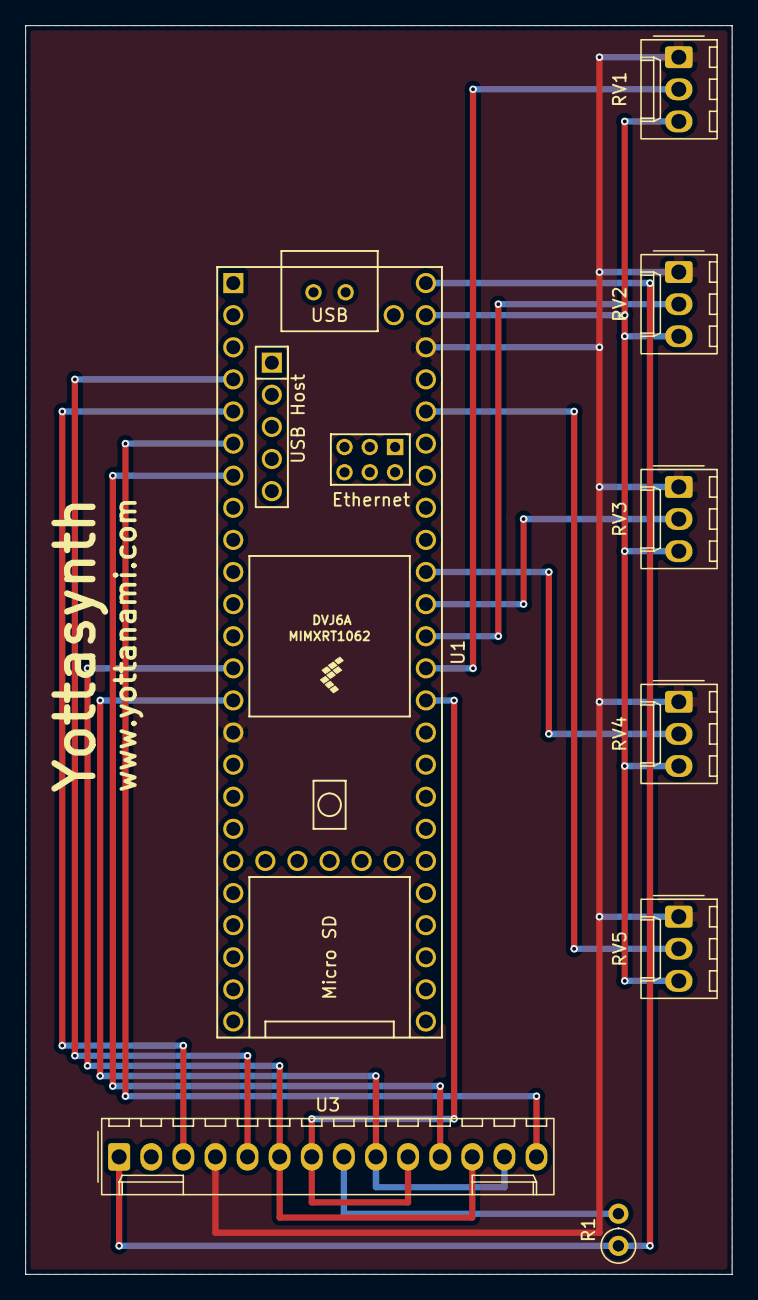
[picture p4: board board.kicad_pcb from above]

Board: 2 copper layers, 55.9 x 98.8 mm, 8 parts (0 on the bottom side), 16 nets.

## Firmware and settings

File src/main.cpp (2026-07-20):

#include <SPI.h>
#include <TFT_eSPI.h>
#include <XPT2046_Touchscreen.h>
#include <lvgl.h>

#include "app_state.h"
#include "audio_setup.h"
#include "control_input.h"
#include "input_test_page.h"
#include "main_menu.h"
#include "performance_engine.h"
#include "play_mode.h"
#include "settings.h"
#include "synth.h"

extern "C" void _reboot_Teensyduino_(void);

namespace {
constexpr uint8_t kTouchCsPin = 5;
constexpr uint8_t kTouchIrqPin = 4;
constexpr uint16_t kDisplayWidth = 480;
constexpr uint16_t kDisplayHeight = 320;
constexpr int16_t kTouchRawXMin = 540;
constexpr int16_t kTouchRawXMax = 3756;
constexpr int16_t kTouchRawYMin = 400;
constexpr int16_t kTouchRawYMax = 3829;
constexpr int16_t kTouchRawMargin = 100;

XPT2046_Touchscreen ts(kTouchCsPin, kTouchIrqPin);
TFT_eSPI tft = TFT_eSPI(kDisplayWidth, kDisplayHeight);

constexpr size_t kDrawBufferSize =
    (kDisplayWidth * kDisplayHeight / 10U) * (LV_COLOR_DEPTH / 8U);
DMAMEM uint32_t draw_buffer[kDrawBufferSize / sizeof(uint32_t)];

unsigned long last_lv_tick_ms = 0;
bool input_test_started = false;
uint8_t touch_press_streak = 0;
uint8_t touch_release_streak = 0;
uint8_t touch_move_streak = 0;
bool touch_confirmed = false;
int16_t last_touch_x = 0;
int16_t last_touch_y = 0;
int16_t last_raw_touch_x = 0;
int16_t last_raw_touch_y = 0;
int16_t last_raw_touch_z = 0;
int16_t pending_touch_x = 0;
int16_t pending_touch_y = 0;
int16_t pending_raw_touch_x = 0;
int16_t pending_raw_touch_y = 0;
int16_t pending_raw_touch_z = 0;

constexpr uint8_t kTouchConfirmCount = 2;
constexpr uint8_t kTouchReleaseCount = 1;
constexpr int16_t kTouchPressurePress = 380;
constexpr int16_t kTouchPressureRelease = 180;
constexpr uint8_t kTouchMoveConfirmCount = 2;
constexpr int16_t kTouchConfirmWindowPx = 18;
constexpr int16_t kTouchMoveWindowPx = 40;

bool touchPointInRange(const TS_Point &point) {
  return point.x >= (kTouchRawXMin - kTouchRawMargin) &&
         point.x <= (kTouchRawXMax + kTouchRawMargin) &&
         point.y >= (kTouchRawYMin - kTouchRawMargin) &&
         point.y <= (kTouchRawYMax + kTouchRawMargin);
}

bool touchPointsClose(int16_t ax, int16_t ay, int16_t bx, int16_t by, int16_t max_delta) {
  return abs(ax - bx) <= max_delta && abs(ay - by) <= max_delta;
}

void storePendingTouch(int16_t x, int16_t y, const TS_Point &point) {
  pending_touch_x = x;
  pending_touch_y = y;
  pending_raw_touch_x = point.x;
  pending_raw_touch_y = point.y;
  pending_raw_touch_z = point.z;
}

void commitTouchSample(int16_t x, int16_t y, const TS_Point &point) {
  last_touch_x = x;
  last_touch_y = y;
  last_raw_touch_x = point.x;
  last_raw_touch_y = point.y;
  last_raw_touch_z = point.z;
  touch_move_streak = 0;
}

void holdLastTouch(lv_indev_data_t *data) {
  input_test_page.updateTouch(true, last_touch_x, last_touch_y, last_raw_touch_x,
                              last_raw_touch_y, last_raw_touch_z);
  data->state = LV_INDEV_STATE_PRESSED;
  data->point.x = last_touch_x;
  data->point.y = last_touch_y;
}

void releaseTouch(lv_indev_data_t *data, bool clear_debug_touch) {
  touch_press_streak = 0;
  touch_release_streak = 0;
  touch_move_streak = 0;
  touch_confirmed = false;
  last_raw_touch_z = 0;
  pending_raw_touch_z = 0;
  if (clear_debug_touch) {
    input_test_page.updateTouch(false, last_touch_x, last_touch_y, last_raw_touch_x,
                                last_raw_touch_y, 0);
  }
  data->state = LV_INDEV_STATE_RELEASED;
}
}

PlayMode play_mode;
Synth synth(&lead_waveform1, &lead_waveform2, &lead_pink, &lead_filter, &lead_envelope);

#if LV_USE_LOG != 0
void print_logs(lv_log_level_t level, const char *buffer) {
  LV_UNUSED(level);
  Serial.println(buffer);
  Serial.flush();
}
#endif

void my_touchpad_read(lv_indev_t *indev, lv_indev_data_t *data) {
  LV_UNUSED(indev);

  const bool irq_active = ts.tirqTouched();
  if (!irq_active) {
    if (touch_confirmed && touch_release_streak + 1U < kTouchReleaseCount) {
      ++touch_release_streak;
      holdLastTouch(data);
      return;
    }

    releaseTouch(data, true);
    return;
  }

  if (!touch_confirmed && !ts.touched()) {
    releaseTouch(data, true);
    return;
  }

  const TS_Point p = ts.getPoint();
  const int16_t pressure_threshold =
      touch_confirmed ? kTouchPressureRelease : kTouchPressurePress;
  const bool valid_touch =
      touchPointInRange(p) && p.z >= pressure_threshold;
  if (!valid_touch) {
    if (touch_confirmed && touch_release_streak + 1U < kTouchReleaseCount) {
      ++touch_release_streak;
      holdLastTouch(data);
      return;
    }

    releaseTouch(data, true);
    return;
  }

  touch_release_streak = 0;

  int x = map(p.y, kTouchRawYMin, kTouchRawYMax, 0, kDisplayWidth - 1);
  int y = map(p.x, kTouchRawXMin, kTouchRawXMax, 0, kDisplayHeight - 1);

  x = constrain(x, 0, kDisplayWidth - 1);
  y = constrain(y, 0, kDisplayHeight - 1);

  if (!touch_confirmed) {
    if (touch_press_streak == 0 ||
        touchPointsClose(x, y, pending_touch_x, pending_touch_y, kTouchConfirmWindowPx)) {
      if (touch_press_streak < kTouchConfirmCount) {
        ++touch_press_streak;
      }
    } else {
      touch_press_streak = 1;
    }

    storePendingTouch(x, y, p);
    input_test_page.updateTouch(false, x, y, p.x, p.y, p.z);
    if (touch_press_streak < kTouchConfirmCount) {
      data->state = LV_INDEV_STATE_RELEASED;
      return;
    }

    touch_confirmed = true;
  } else if (!touchPointsClose(x, y, last_touch_x, last_touch_y, kTouchMoveWindowPx)) {
    if (touch_move_streak == 0 ||
        touchPointsClose(x, y, pending_touch_x, pending_touch_y, kTouchConfirmWindowPx)) {
      if (touch_move_streak < kTouchMoveConfirmCount) {
        ++touch_move_streak;
      }
    } else {
      touch_move_streak = 1;
    }

    storePendingTouch(x, y, p);
    input_test_page.updateTouch(true, x, y, p.x, p.y, p.z);
    if (touch_move_streak < kTouchMoveConfirmCount) {
      holdLastTouch(data);
      return;
    }
  } else {
    touch_move_streak = 0;
  }

  commitTouchSample(x, y, p);
  input_test_page.updateTouch(true, x, y, p.x, p.y, p.z);
  data->state = LV_INDEV_STATE_PRESSED;
  data->point.x = x;
  data->point.y = y;
}

void my_disp_flush(lv_display_t *display, const lv_area_t *area, uint8_t *px_map) {
  LV_UNUSED(display);

  const uint32_t width = area->x2 - area->x1 + 1U;
  const uint32_t height = area->y2 - area->y1 + 1U;

  tft.startWrite();
  tft.setAddrWindow(area->x1, area->y1, width, height);
  tft.pushColors(reinterpret_cast<uint16_t *>(px_map), width * height, true);
  tft.endWrite();

  lv_display_flush_ready(display);
}

void setup() {
  Serial.begin(115200);

  lv_init();
  tft.begin();
  tft.setRotation(3);
  ts.begin();
  ts.setRotation(0);
  pinMode(kTouchIrqPin, INPUT_PULLUP);

#if LV_USE_LOG != 0
  lv_log_register_print_cb(print_logs);
#endif

  lv_display_t *display = lv_display_create(kDisplayWidth, kDisplayHeight);
  lv_display_set_flush_cb(display, my_disp_flush);
  lv_display_set_buffers(display, draw_buffer, nullptr, sizeof(draw_buffer),
                         LV_DISPLAY_RENDER_MODE_PARTIAL);

  lv_indev_t *indev = lv_indev_create();
  lv_indev_set_type(indev, LV_INDEV_TYPE_POINTER);
  lv_indev_set_read_cb(indev, my_touchpad_read);

  main_menu.render();

  control_input.begin();
  const bool audio_codec_ready = setupAudio();
  AppState::instance().updateAudioStatus(audio_codec_ready, false);
  synth.setup();
  setOutputVolume(AppState::instance().audio.output_volume);
  play_mode.setup();
  performance_engine.begin(&synth);

  last_lv_tick_ms = millis();
}

void loop() {
  AppState::instance().refreshTransientStatus(millis());
  const Mode mode = Settings::getInstance()->getMode();

  if (mode == Mode::INPUT_TEST) {
    input_test_page.setProbeEnabled(true);
    if (!input_test_started) {
      input_test_page.begin();
      input_test_started = true;
    }
    input_test_page.loop();
  } else {
    input_test_page.setProbeEnabled(false);
    input_test_started = false;

    control_input.update();
    for (uint8_t index = 0; index < ControlInput::kPotCount; ++index) {
      float value = 0.0f;
      if (control_input.consumePotChange(index, value)) {
        main_menu.handlePotChange(index, value);
      }
    }

    play_mode.loop();
    performance_engine.update();
    synth.applyPatch(AppState::instance().patch);
    applyFxState(AppState::instance().fx);
    synth.loop();
    AppState::instance().updateAudioStatus(AppState::instance().audio.codec_ready,
                                           synth.isSelfTestActive());
  }

  if (Serial.available()) {
    const int c = Serial.read();
    if (c == '!') {
      Serial.println("Rebooting to bootloader...");
      Serial.flush();
      delay(10);
      _reboot_Teensyduino_();
    }
  }

  main_menu.loop();

  const unsigned long now_ms = millis();
  const unsigned long elapsed_ms = now_ms - last_lv_tick_ms;
  if (elapsed_ms > 0) {
    lv_tick_inc(elapsed_ms);
    last_lv_tick_ms = now_ms;
  }
  lv_timer_handler();
}

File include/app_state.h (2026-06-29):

#ifndef APP_STATE_H
#define APP_STATE_H

#include <Arduino.h>

#include "settings.h"

enum class PageId : uint8_t {
  PLAY = 0,
  OSC_MIX,
  FILTER_AMP,
  MOD,
  FX,
  ARP,
  SEQ,
  SETTINGS
};

enum class LfoTarget : uint8_t {
  OFF = 0,
  FILTER,
  PITCH
};

enum class OscWave : uint8_t {
  SAW = 0,
  SINE,
  SQUARE,
  TRIANGLE
};

enum class ArpMode : uint8_t {
  UP = 0,
  DOWN,
  UP_DOWN,
  RANDOM
};

enum class FxMode : uint8_t {
  ECHO = 0,
  REVERB,
  DRIVE
};

enum class ClockSource : uint8_t {
  INTERNAL = 0,
  EXTERNAL
};

enum class TuningId : uint8_t {
  STANDARD = 0,
  SHUR,
  ABUATA,
  DASHTI,
  BAYAT_E_TORK,
  AFSHARI,
  SEGAH,
  CHAHARGAH,
  HOMAYUN,
  BAYAT_E_ESFAHAN,
  NAVA,
  MAHUR,
  RAST_PANJGAH
};

struct PatchState {
  float osc1_mix = 0.85f;
  float osc2_mix = 0.60f;
  OscWave osc1_wave = OscWave::SAW;
  OscWave osc2_wave = OscWave::SAW;
  float noise_mix = 0.05f;
  int8_t octave_index = 2;
  float detune = 0.08f;
  float cutoff = 0.72f;
  float resonance = 0.20f;
  float attack = 0.05f;
  float decay = 0.22f;
  float sustain = 0.72f;
  float release = 0.24f;
  float lfo_rate = 0.22f;
  float lfo_depth = 0.12f;
  LfoTarget lfo_target = LfoTarget::FILTER;
  float glide = 0.08f;
  float bend_range = 0.25f;
  TuningId tuning = TuningId::STANDARD;
};

struct TransportState {
  uint16_t bpm = 120;
  bool running = false;
  float swing = 0.0f;
  uint8_t step_index = 0;
  ClockSource clock_source = ClockSource::INTERNAL;
  bool ext_clock_present = false;
};

struct ArpState {
  bool enabled = false;
  bool latch = false;
  ArpMode mode = ArpMode::UP;
  uint8_t octave_range = 1;
  uint8_t division = 1;
  uint8_t gate = 70;
};

struct EchoFxState {
  float mix = 0.34f;
  float time = 0.30f;
  float feedback = 0.42f;
  float ratio = 0.62f;
  float smear = 0.18f;
};

struct ReverbFxState {
  float mix = 0.28f;
  float size = 0.56f;
  float damping = 0.42f;
  float predelay = 0.12f;
  float tone = 0.58f;
};

struct DriveFxState {
  float mix = 0.38f;
  float drive = 0.44f;
  float tone = 0.68f;
  float crush = 0.20f;
  float level = 0.60f;
};

struct FxState {
  bool enabled = false;
  FxMode mode = FxMode::ECHO;
  EchoFxState echo;
  ReverbFxState reverb;
  DriveFxState drive;
};

struct SequenceStep {
  bool active = false;
  bool tie = false;
  uint8_t note = 60;
  uint8_t gate = 75;
};

struct SequencerState {
  bool enabled = false;
  bool record_armed = false;
  uint8_t length = 16;
  uint8_t playhead = 0;
  uint8_t selected_step = 0;
  uint8_t visible_bank = 0;
  SequenceStep steps[16];
};

struct UiState {
  PageId page = PageId::PLAY;
  bool dirty = true;
  bool show_input_test = false;
  bool confirm_clear_sequence = false;
};

struct MidiStatus {
  bool connected = false;
  uint16_t vendor_id = 0;
  uint16_t product_id = 0;
  bool note_recent = false;
  uint8_t last_note = 0;
  uint8_t last_velocity = 0;
  unsigned long last_note_ms = 0;
};

struct AudioStatus {
  bool codec_ready = false;
  bool self_test_active = false;
  float output_volume = 0.50f;
};

class AppState {
 public:
  static AppState &instance();

  PatchState patch;
  TransportState transport;
  ArpState arp;
  FxState fx;
  SequencerState sequencer;
  UiState ui;
  MidiStatus midi;
  AudioStatus audio;

  void setPage(PageId page);
  void setInputTestVisible(bool visible);
  void markDirty();
  Mode currentMode() const;
  void updateMidiDevice(bool connected, uint16_t vendor_id, uint16_t product_id);
  void registerMidiNote(uint8_t note, uint8_t velocity);
  void refreshTransientStatus(unsigned long now_ms);
  void updateAudioStatus(bool codec_ready, bool self_test_active);
  void setOutputVolume(float volume);

 private:
  AppState();
};

const char *pageTitle(PageId page);
const char *arpModeLabel(ArpMode mode);
const char *fxModeLabel(FxMode mode);
const char *clockSourceLabel(ClockSource source);
const char *lfoTargetLabel(LfoTarget target);
const char *oscWaveLabel(OscWave wave);
const char *tuningLabel(TuningId tuning);
uint8_t tuningCount();

#endif

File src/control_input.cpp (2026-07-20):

#include "control_input.h"

#include "knob_pins.h"

namespace {
constexpr uint16_t kAnalogMax = 4095;
constexpr float kSmoothing = 0.20f;
constexpr float kPotThreshold = 0.015f;
}

void ControlInput::begin() {
  for (const uint8_t pin : KnobPins::kKnobPins) {
    pinMode(pin, INPUT_DISABLE);  // pure analog input, no digital keeper
  }

  analogReadResolution(12);
  analogReadAveraging(8);

  for (uint8_t index = 0; index < kPotCount; ++index) {
    const uint16_t raw = readKnob(KnobPins::kKnobPins[index]);
    raw_values_[index] = raw;
    const float normalized = static_cast<float>(raw) / static_cast<float>(kAnalogMax);
    filtered_values_[index] = normalized;
    pending_values_[index] = normalized;
  }
}

void ControlInput::update() {
  for (uint8_t index = 0; index < kPotCount; ++index) {
    const uint16_t raw = readKnob(KnobPins::kKnobPins[index]);
    raw_values_[index] = raw;

    const float normalized = static_cast<float>(raw) / static_cast<float>(kAnalogMax);
    const float filtered = filtered_values_[index] + ((normalized - filtered_values_[index]) * kSmoothing);
    filtered_values_[index] = filtered;

    if (fabsf(filtered - pending_values_[index]) >= kPotThreshold) {
      pending_values_[index] = filtered;
      pending_changes_[index] = true;
    }
  }
}

bool ControlInput::consumePotChange(uint8_t index, float &value) {
  if (index >= kPotCount || !pending_changes_[index]) {
    return false;
  }

  pending_changes_[index] = false;
  value = pending_values_[index];
  return true;
}

float ControlInput::potValue(uint8_t index) const {
  if (index >= kPotCount) {
    return 0.0f;
  }
  return filtered_values_[index];
}

uint16_t ControlInput::rawChannelValue(uint8_t index) const {
  if (index >= kPotCount) {
    return 0;
  }
  return raw_values_[index];
}

uint16_t ControlInput::readKnob(uint8_t pin) const {
  analogRead(pin);  // discard first sample after the ADC switches channel

  uint32_t total = 0;
  for (uint8_t sample = 0; sample < 4; ++sample) {
    total += analogRead(pin);
  }

  return static_cast<uint16_t>(total / 4U);
}

ControlInput control_input;

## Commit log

2026-01-29 Remove old board and update README
    [board.kicad_pcb, board.kicad_sch]
2026-04-26 Update board files and scan knob rotates
    [board.kicad_pcb, freerouting.dsn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]
2026-04-30 Fix ui and sequencer issues
    [input_test_page.cpp, main.cpp]
2026-05-01 Fix after arp issue
    [main.cpp]
2026-07-20 Update code for board v2
    [board.kicad_pcb, board.kicad_sch]
2026-07-20 Add knob pins and move board to old
